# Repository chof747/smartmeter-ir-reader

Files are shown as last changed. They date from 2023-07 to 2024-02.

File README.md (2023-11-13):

## Smartmeter IR Reader/Writer

This is an implementation of the smart reader concept created by [volkszaehler.org](https://wiki.volkszaehler.org/hardware/controllers/ir-schreib-lesekopf-ttl-ausgang).

It has been modified as follows:

- Replaced 13k resistors by 10k (as I have a lot of them in stock)
- Added an RJ11 connector with 4 pins as a connector to the microcontroller unit

This board is intended to interface with a Microcontroller unit via an RJ11 connector.

## Schematic & Board Layout

Schematic

Board Layout

## Revision History:
- **v1.0**: Initial version (Produced: 19.08.2023; not assembled)
- **v1.1**: Corrected RJ11 socket connector (Produced: 19.09.2023; First Assembly: 06.10.2023))
- **v1.2**: Corrected misorientation of Q1/Q2 transistor pins, Board cutout and added Pin descriptions (Produced 15.10.2023; Asembled: 10.11.2023 - successfully)

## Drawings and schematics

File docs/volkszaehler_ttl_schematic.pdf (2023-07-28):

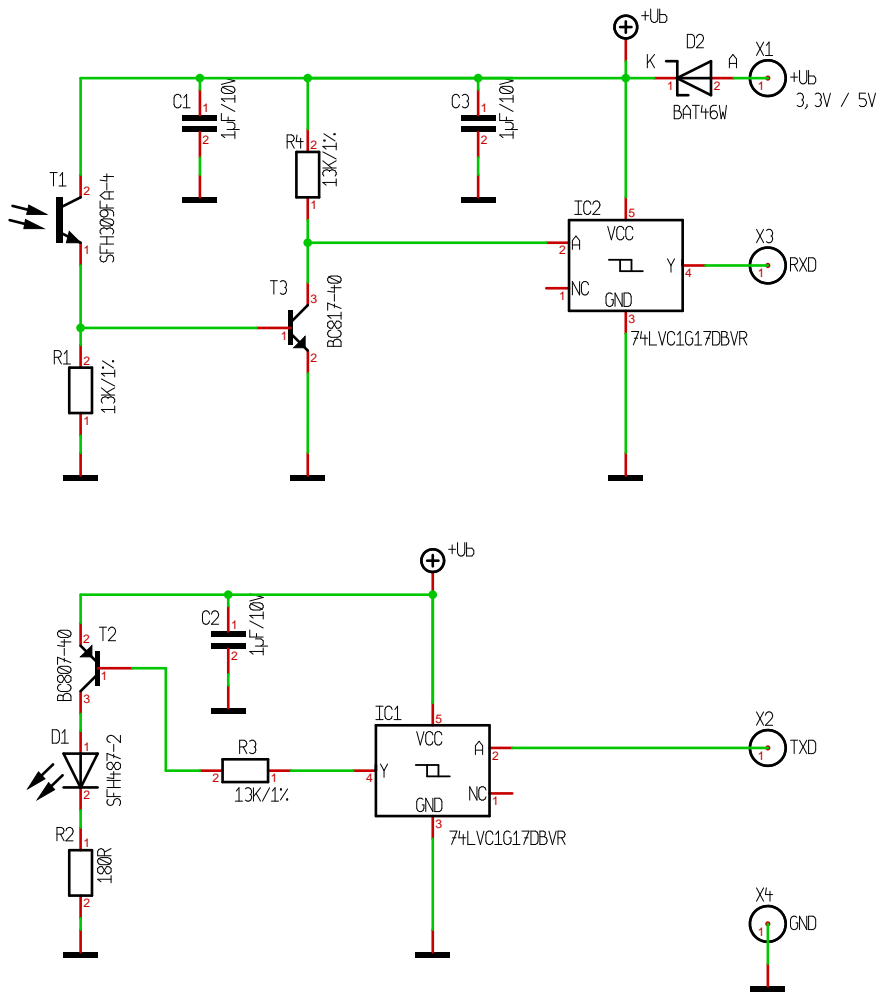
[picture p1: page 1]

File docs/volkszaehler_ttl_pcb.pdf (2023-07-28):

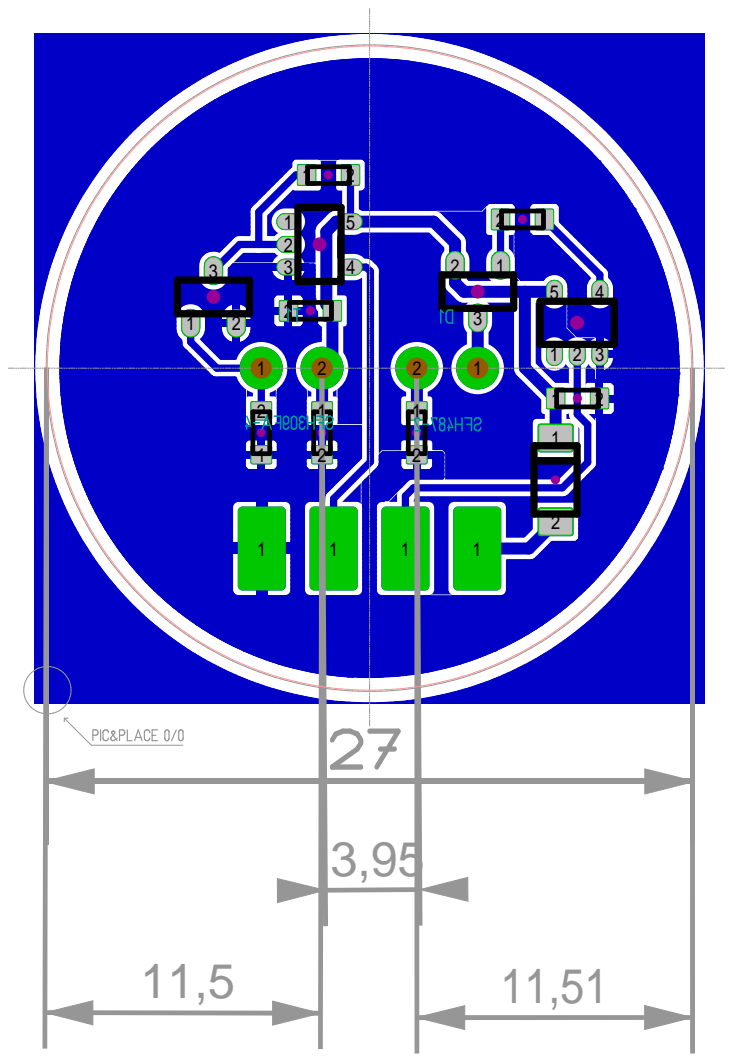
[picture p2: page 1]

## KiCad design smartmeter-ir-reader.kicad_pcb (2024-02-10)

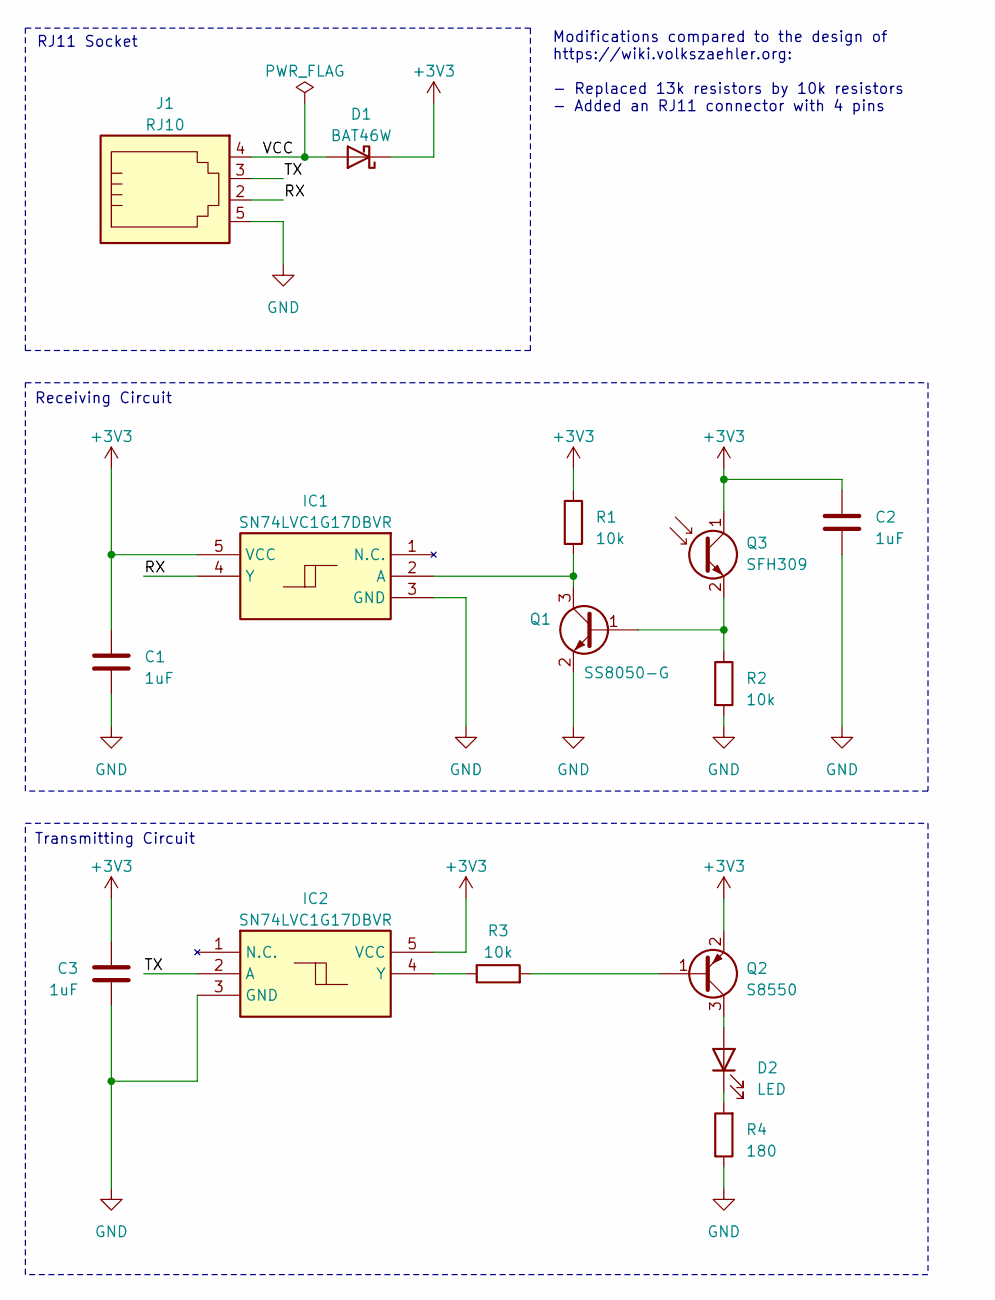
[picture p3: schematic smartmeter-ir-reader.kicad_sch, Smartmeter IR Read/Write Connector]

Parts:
C1, C2, C3: 1uF; C_0603_1608Metric_Pad1.08x0.95mm_HandSolder
D1: BAT46W; D_SOD-123
D2: LED; LED_D3.0mm_Clear
IC1, IC2: SN74LVC1G17DBVR; SOT95P270X145-5N; Manufacturer_Part_Number SN74LVC1G17DBVR; Mouser Part Number 595-SN74LVC1G17DBVR
J1: RJ10; RJ12_Amphenol_54601
Q1: SS8050-G; SOT-23
Q2: S8550; SOT-23
Q3: SFH309; LED_D3.0mm_Clear
R1, R2, R3: 10k; R_0603_1608Metric_Pad0.98x0.95mm_HandSolder
R4: 180; R_0603_1608Metric_Pad0.98x0.95mm_HandSolder

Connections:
+3V3: C1.1, C2.1, C3.1, D1.1 (K), IC1.5 (VCC), IC2.5 (VCC), Q2.2 (E), Q3.1 (C), R1.1
/RX: IC1.4 (Y), J1.2
/TX: IC2.2 (A), J1.3
/VCC: D1.2 (A), J1.4
GND: C1.2, C2.2, C3.2, IC1.3 (GND), IC2.3 (GND), J1.5, Q1.2 (E), R2.2, R4.1
unnamed: D2.2 (A), Q2.3 (C)
unnamed: D2.1 (K), R4.2
unnamed: IC1.2 (A), Q1.3 (C), R1.2
unnamed: IC2.4 (Y), R3.1
unnamed: Q1.1 (B), Q3.2 (E), R2.1
unnamed: Q2.1 (B), R3.2

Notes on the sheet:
Receiving Circuit
Transmitting Circuit
Modifications compared to the design of https://wiki.volkszaehler.org: - Replaced 13k resistors by 10k resistors - Added an RJ11 connector with 4 pins
RJ11 Socket

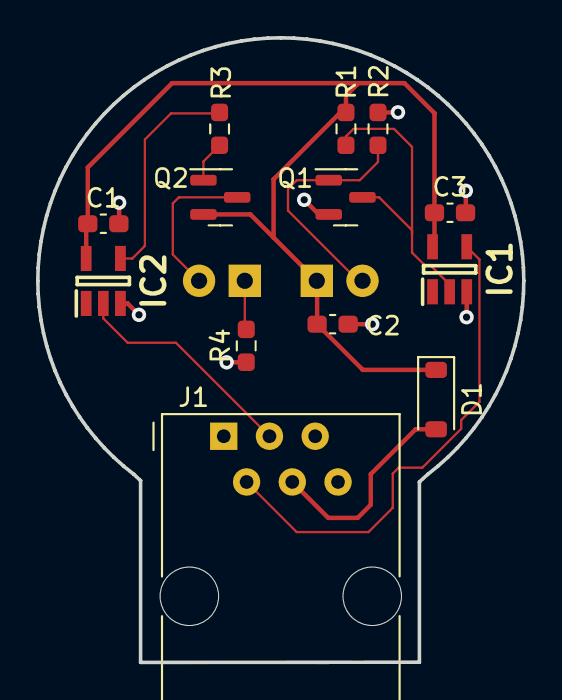
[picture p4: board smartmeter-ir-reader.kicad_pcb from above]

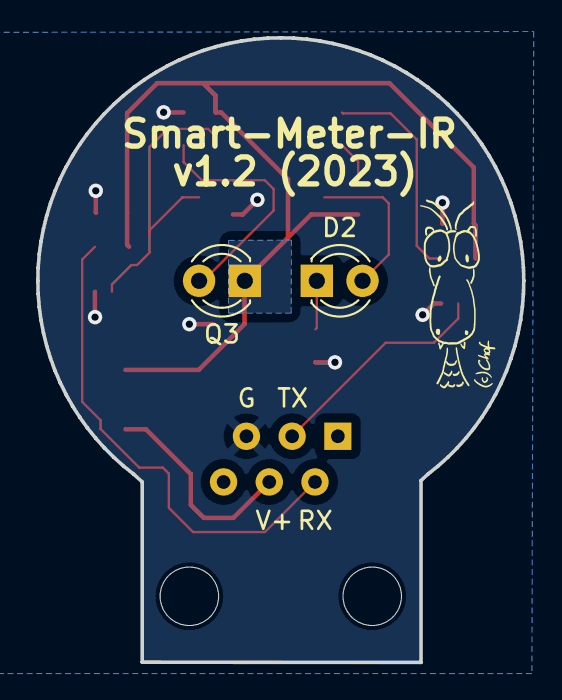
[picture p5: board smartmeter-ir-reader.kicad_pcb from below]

Board: 2 copper layers, 27.0 x 34.7 mm, 15 parts (2 on the bottom side), 11 nets.

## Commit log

2023-07-28 Initial commit including docs for volkszaehler pcb and schematics
    [smartmeter-ir-reader.kicad_pcb, smartmeter-ir-reader.kicad_sch]
2023-08-03 Initial version
    [smartmeter-ir-reader.kicad_pcb, smartmeter-ir-reader.kicad_sch]
2023-08-19 Initial version Revision 1.0
    [smartmeter-ir-reader.kicad_pcb, smartmeter-ir-reader.kicad_sch]
2023-09-15 corrected RJ12 socket Connector
    [smartmeter-ir-reader.kicad_pcb, smartmeter-ir-reader.kicad_sch]
2023-10-06 First Assembly
2023-10-11 Reformatted schematic
    [smartmeter-ir-reader.kicad_sch]
2023-10-11 Added board drawings to readme
2023-10-15 V1.2 with corrected transistor layouts
    [smartmeter-ir-reader.kicad_pcb, smartmeter-ir-reader.kicad_sch]
2023-11-13 successfully corrected transistor fix and assembled
2024-02-10 added board outline
    [smartmeter-ir-reader.kicad_pcb]
